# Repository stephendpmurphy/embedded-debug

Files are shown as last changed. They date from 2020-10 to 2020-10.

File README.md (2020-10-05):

# embedded-debug


This debug board allows two unused traces of a 10pin (1.27mm pitch) connector to be broken out and used for a UART RX & TX line from the target MCU. These UART lines can be used by the Target to send debug print statements through the programming connector, to the USB bridge, and then displayed on a PC terminal. This is useful since board space is no longer needed on the target for any sort of extra headers or test pads for debug data.

This is a revamp of an existing project [ARM-Debug](https://github.com/stephendpmurphy/ARM-Debug) which was originally designed in Eagle CAD, while this project is designed using [KiCAD](https://kicad-pcb.org/)

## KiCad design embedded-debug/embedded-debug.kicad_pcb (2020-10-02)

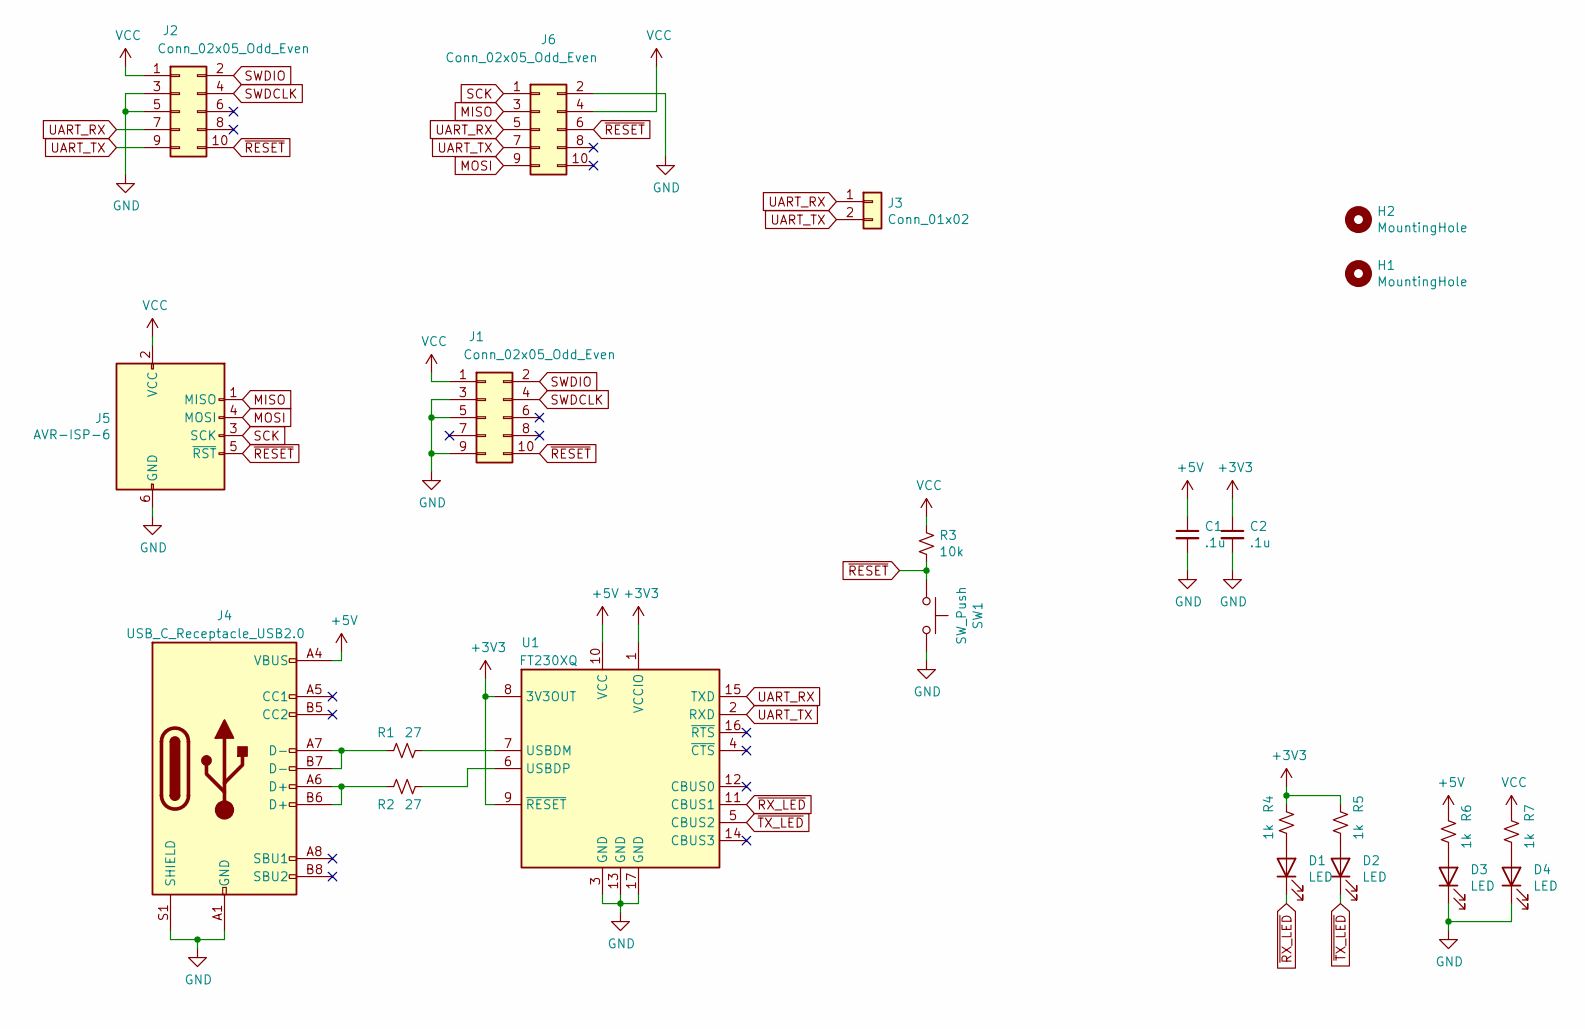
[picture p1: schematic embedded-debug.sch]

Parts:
C1, C2: .1u; C_0402_1005Metric
D1, D2, D3, D4: LED; LED_0603_1608Metric
H1, H2: MountingHole; MountingHole_2mm
J1, J2, J6: Conn_02x05_Odd_Even; PinHeader_2x05_P1.27mm_Vertical_SMD
J3: Conn_01x02; PinHeader_1x02_P2.54mm_Horizontal
J4: USB_C_Receptacle_USB2.0; USB_C_Receptacle_GCT_USB4085
J5: AVR-ISP-6; PinHeader_2x03_P2.54mm_Vertical
R1, R2: 27; R_0402_1005Metric
R3: 10k; R_0402_1005Metric
R4, R5, R6, R7: 1k; R_0402_1005Metric
SW1: SW_Push; Panasonic_EVQPUJ_EVQPUA
U1: FT230XQ; QFN-16-1EP_4x4mm_P0.65mm_EP2.1x2.1mm

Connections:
+3V3: C2.1, R4.1, R5.1, U1.1 (VCCIO), U1.8 (3V3OUT), U1.9 (~RESET)
+5V: C1.1, J4.A4 (VBUS), J4.A9 (VBUS), J4.B4 (VBUS), J4.B9 (VBUS), R6.1, U1.10 (VCC)
GND: C1.2, C2.2, D3.1 (K), D4.1 (K), J1.3, J1.5, J1.9, J2.3, J2.5, J4.A1 (GND), J4.A12 (GND), J4.B1 (GND), J4.B12 (GND), J4.S1 (SHIELD), J5.6 (GND), J6.2, SW1.2, U1.3 (GND), U1.13 (GND), U1.17 (GND)
MISO: J5.1 (MISO), J6.3
MOSI: J5.4 (MOSI), J6.9
unnamed: D1.2 (A), R4.2
unnamed: D2.2 (A), R5.2
unnamed: D3.2 (A), R6.2
unnamed: D4.2 (A), R7.2
unnamed: J4.A6 (D+), J4.B6 (D+), R2.1
unnamed: J4.A7 (D-), J4.B7 (D-), R1.1
unnamed: R1.2, U1.7 (USBDM)
unnamed: R2.2, U1.6 (USBDP)
SCK: J5.3 (SCK), J6.1
SWDCLK: J1.4, J2.4
SWDIO: J1.2, J2.2
UART_RX: J2.7, J3.1, J6.5, U1.15 (TXD)
UART_TX: J2.9, J3.2, J6.7, U1.2 (RXD)
VCC: J1.1, J2.1, J5.2 (VCC), J6.4, R3.1, R7.1
~RESET: J1.10, J2.10, J5.5 (~RST), J6.6, R3.2, SW1.1
~RX_LED: D1.1 (K), U1.11 (CBUS1)
~TX_LED: D2.1 (K), U1.5 (CBUS2)

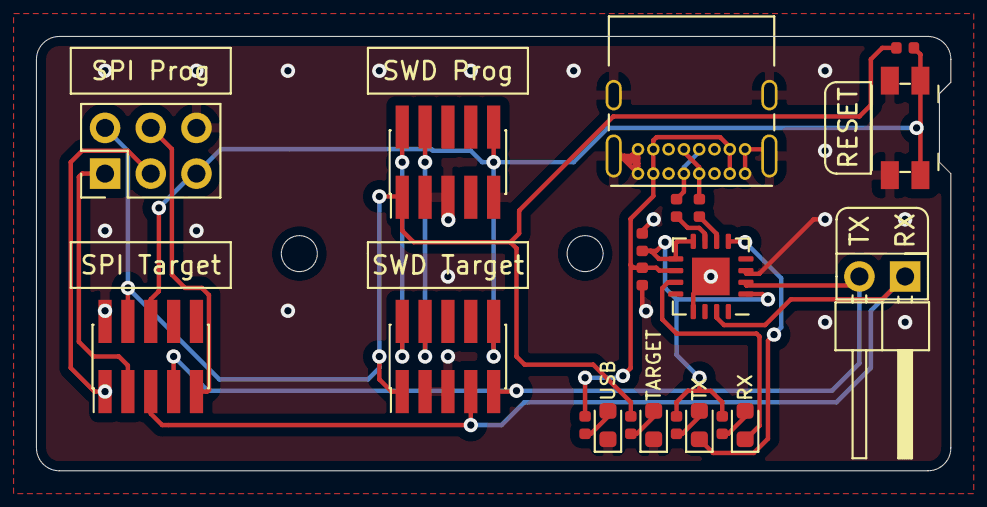
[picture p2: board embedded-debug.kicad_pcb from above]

Board: 2 copper layers, 50.8 x 24.1 mm, 23 parts (0 on the bottom side), 22 nets.

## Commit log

2020-09-26 First pass at routing
    [embedded-debug.kicad_pcb, embedded-debug.sch]
2020-10-02 Committing and order rev-1
    [embedded-debug-B_Cu.gbr, embedded-debug-B_Mask.gbr, embedded-debug-B_Paste.gbr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]

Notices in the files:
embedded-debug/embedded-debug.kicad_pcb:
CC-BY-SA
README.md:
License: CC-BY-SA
